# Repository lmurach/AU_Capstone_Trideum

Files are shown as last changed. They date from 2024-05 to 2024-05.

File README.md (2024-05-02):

# Cyber-Physical Teaching Kit
## General Description

The Cyber-Physical Teaching Kit (CPTK) is a miniature, modular building with a fully-functional control
system. The belief is that by building a robust model, students will better understand how to think about
potential cyber attacks. The code is mostly written in python for the Raspberry Pi 4, along with C++ code
for the Arduino. Students are more likely to encounter python and Arduino coding throughout high school
or college, which is why these two languages were chosen.

To see the full documentation, see the documentation PDF on our Github.

## Features

+ Sturdy, lightweight 3D printed frame with files available for re-printing
+ Accurate elevator with button controls on each floor and a re-calibration function
+ Temperature monitoring with an HVAC and duct work system for air conditioning
+ Security door system using RFID badges with a working door
+ Lights with individual floor motion detection
+ Full database for logging events, errors, and storing user configurations
+ Security assessment in pdf form detailing vulnerabilities, mitigation, and impact

## Links

+ [Github for open source code under the MIT license](https://github.com/lmurach)
+ [Security Assessment PDF](https://github.com/lmurach/AU_Capstone_Trideum/blob/ui_dev/TrideumCapstoneSecurityAssessment.pdf)

## Block Diagram



# Getting Started

An already constructed version of the CPTK was built for Trideum Corporation. The following are
instructions for running the program on the existing system.

## Running the App with a Monitor

This is the most ideal way to view the application, as the GUI is visible and intractable. If a monitor is
not available, see the next section.
1. Plug an HDMI cable, keyboard, and mouse into the Raspberry Pi and power the system. The Pi will
boot automatically.
2. Open the console using the icon at the top right of the screen or with the keyboard shortcut
CTRL+ALT+T
3. Run the application with the following command:
sudo python3 AU Capstone Trideum/application.py

## Running the App without a Monitor
Note that the GUI will not be accessible with this method.
1. Plug an Ethernet cable into the Pi and power the system. The Pi will boot automatically. Make sure
your Ethernet settings allow internet and file sharing.
2. For Windows users, install PuTTy.
3. Run the .exe file and enter in the following for the host name, then press enter:
```
cptk@raspberrypi.local
```


4. For macOS/Linux users, open the command prompt and enter the following command:
```
ssh cptk@[raspberrypi ip address]
```
To get the IP address, run ipconfig in the command line. Alternatively, follow the instructions for
Windows and install PuTTy.
5. Once connected, the command line will prompt for a password. The password for the cptk user is
CPTK-Project
The text will not show up while typing the password, but hitting enter will connect to the Pi.
6. Run the application with the following command:
```
sudo python3 AU Capstone Trideum/application.py -platform offscreen
```

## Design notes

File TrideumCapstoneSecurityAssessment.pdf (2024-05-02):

1

# Trideum Cyber-Physical Learning Model Security Assessment

### Assessment by Chris Stickney Last updated 4/25/2024

Cyber-Physical Learning Model by Wesley Cooke, Lauren Murach,

### Brycen Havens, and Chris Stickney

2

## Executive Summary

Since our system will be offline the majority of the time, the primary vulnerabilities this system

has are physical, only able to be taken advantage of by insiders and intruders. The primary

vulnerabilities found in the building include two critical vulnerabilities in the RFID door which

may allow illicit access to the restricted area it protects, and vulnerabilities in the temperature

sensors, which can lead to improper measurements being sent to the controller. These HVAC

vulnerabilities can lead to damage of expensive computational assets if the temperature gets too

cold or warm. Lastly, the motion sensors in use can be circumvented if they are unable to detect

thermal signatures moving, allowing intruders to not trigger alarms in the building after hours.

These issues are the most troublesome issues found, and should be addressed immediately to

improve site security and reduce risk.

3

### Contents

4

## Flipper Zero Can Bypass RFID Door Security

Threat Actor: Building Intruders and Insiders

Vulnerability: The Flipper Zero is a multi-purpose tool, with one of its capabilities being reading,

saving, and emulating RFID and NFC tags. This means that a user with a Flipper Zero is capable

of opening the RFID door without an RFID or NFC tag with access to the door, provided they

are able to read the RFID or NFC tag with the appropriate permissions to open the door.

Mitigation: Implement more complex RFID and NFC systems, such as an RFID or NFC system

that needs two RFID or NFC tags from the same card to gain access. It should also be noted that

the process the Flipper Zero uses to read RFID and NFC cards takes several seconds, making

successfully reading an RFID or NFC card more challenging for malicious actors. In addition,

the Flipper Zero tends to cause errors in the RFID reader code, as occasionally the signal sent is

not identical to the copied RFID or NFC tag.

Impact: Malicious actors can utilize this to bypass secure doors, gaining access to restricted

areas. Any systems located in these restricted areas will be vulnerable to physical tampering.

5

## PIR Motion Sensors Can Be Bypassed With Thermal

## Insulation

Threat Actor: Building Intruders and Insiders

Vulnerability: PIR motion sensors are unable to detect motion from objects with masked thermal

signatures since PIR sensors rely upon thermal changes to trigger the sensor.

Mitigation: Other forms of motion detection may be used, such as Microwave motion sensors,

which send a signal if a significant change is detected in the distance between the sensor and an

object. Microwave sensors can be extremely sensitive however and can read data through walls

at times. Other forms of motion sensors exist which have different upsides and downsides than

PIR sensors and Microwave sensors.

Impact: Security alerts for people intruding on the building after hours can be prevented, giving

malicious actors free access to the building (minus restricted areas), where they are free to do

what they please.

6

## Temperature Sensors Are Vulnerable to Physical

## Manipulation

Threat Actor: Building Intruders and Insiders

Vulnerability: TC74 temperature sensor is a contact-based temperature sensor, meaning very hot

or very cold objects may be applied to the sensor to manipulate readings and interrupt HVAC

operations.

Mitigation: Change the TC74 sensors out to a non-contact-based temperature, which operates by

reading infrared radiation of the surroundings. These can be interrupted by objects that cloak

thermal signatures being placed around the sensor, like an acrylic dome covering the sensor. The

best solution for both of these vulnerabilities is to place the temperature sensors in concealed, out

of reach locations to prevent tampering.

Impact: HVAC controls being manipulated can lead to uncomfortable working environments, or

in more extreme cases, damaged computer systems if the temperature becomes much too hot or

too cold. In this case, this can cause large financial loss of assets.

7

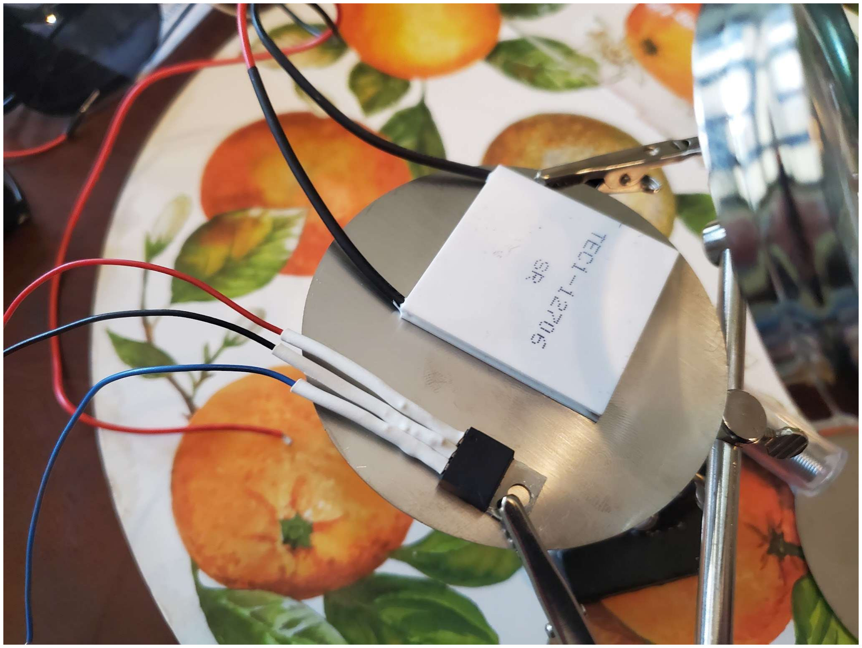
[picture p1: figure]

This image shows a similar contact based temperature sensor on a hot plate. A similar setup

could be used to manipulate the TC74 into running the HVAC too much. The opposite could also

occur if a cold object was attached to the TC74.

8

## System Stability Could Be Crippled By Online Attacks

## Which Ruin System Performance

Threat Actor: Malicious Outsiders and Insiders

Vulnerability: The control software’s operation could be interrupted by applications with high

performance draw, which could be activated by outside users to interrupt the system.

Mitigation: Critical cyber physical systems which can remain offline should remain offline to

prevent connections. The Raspberry Pi should be placed within a secure location to better protect

against unauthorized manipulation. Alternatively, if the system must be connected to the internet,

ensure proper security practices are in place and for added security against attacks, implement an

IDPS that can cut off connections. As a final line of protection, implementing revised code that

can improve the average Lyapunov stability of the system while under external stress should be

considered. This should not be an issue, as the system only needs to momentarily touch the

internet to set the system time.

Impact: If systems have inadequate safeguards against online attacks such as DDoS attacks or

False Data Injection attacks, the system’s performance and behavior could be altered, leading to

the system running behind or breaking entirely, needed to be restarted.

9

## Reed Switches May Be Manipulated With Strong Enough

## Magnets

Threat Actor: Insiders and Building Intruders

Vulnerability: Reed switches can be easily activated if not properly concealed or if too sensitive.

Magnets can be affixed to extra surfaces to make systems malfunction.

Mitigation: Getting reed switches with less sensitivity may work, but a better solution to ensure

the operation of the elevators is not interrupted is to make sure applying magnets in locations that

may disrupt the elevator is very challenging. Hall sensors would also have issues since they also

rely upon magnetic fields.

Impact: Strong enough magnets placed within or around the elevator cabin could interfere with

the reed sensors, sending faulty signals to the controller which may result in the elevator

stopping in the wrong spots.

10

## Physical Access to Wires May Allow Replay Attacks

Threat Actor: Insiders and Building Intruders

Vulnerability: If attackers are able to identify which wires are used for SPI or I2C, they could

mimic signals sent by sensors, such as the temperature sensor or RFID card reader. This can lead

to system malfunctions due to the system receiving erroneous data from malicious devices. It

should also be noted that the motion detection system also faces this issue, as an external device

could send a constant high or low signal to manipulate the program into thinking there is motion

when there isn’t or there isn’t motion when there is.

Mitigation: The best way to mitigate this threat is to ensure that all wiring is protected from

tampering. Exposed wiring can be disconnected from their sensors and connected to a malicious

device which sends false information. New log alerts could be made which record when

unreasonable values are detected for the RFID reader or temperature sensors.

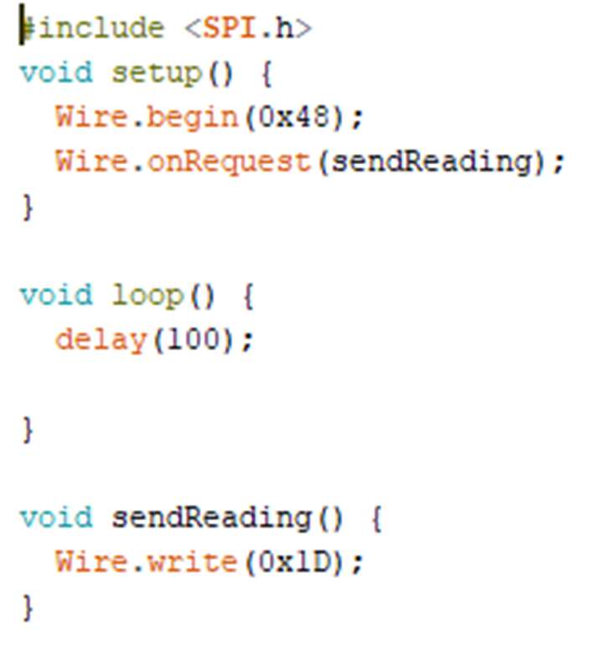
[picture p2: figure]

11

This simple program is able to send a false temperature reading of 29°C, which equals around

84°F. It should be noted that this program is run on an Arduino which uses 3.3V logic like a

Raspberry Pi. The erroneous value being sent will force the HVAC system into cooling the floor

with the TC74 with address 0x48. This code could be altered to send a constant value below the

activation threshold to prevent the HVAC from turning on.

Impact: HVAC controls being manipulated can lead to uncomfortable working environments, or

in more extreme cases, damaged computer systems if the temperature becomes much too hot or

too cold. In this case, this can cause large financial loss of assets. A similar attack using more

advanced techniques may also be performed on the RFID door, where information could be

captured and retransmitted by a third party device, allowing the door to open without an RFID

device being used. This allows illicit access to restricted areas that are supposed to be protected

by these doors, which can lead to restricted system tampering.

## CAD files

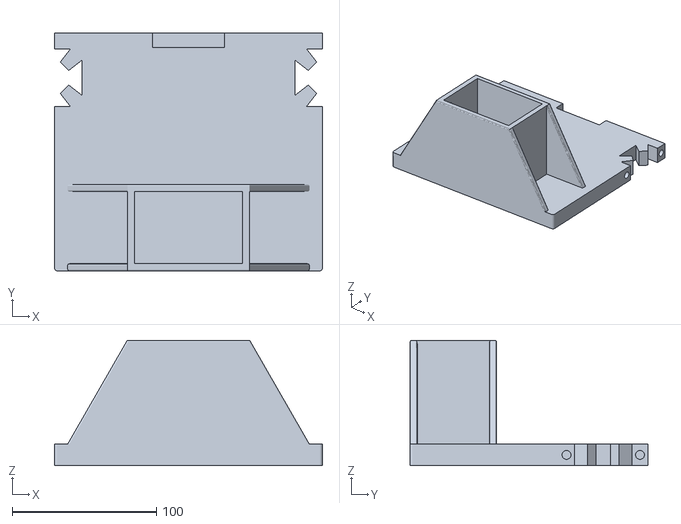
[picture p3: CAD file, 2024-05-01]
allFrameParts/Base Frame/Elevator Base (x1).stl
186.0 x 165.1 x 87.0

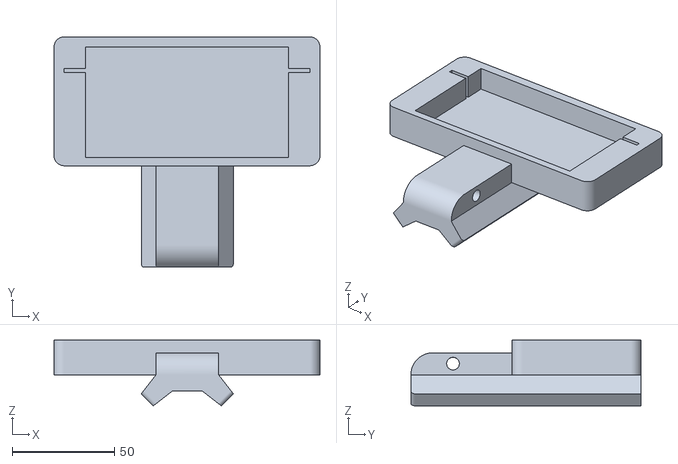
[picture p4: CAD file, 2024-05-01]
allFrameParts/Basement Floor/HVAC Mount (x1).stl
130.0 x 112.5 x 32.1

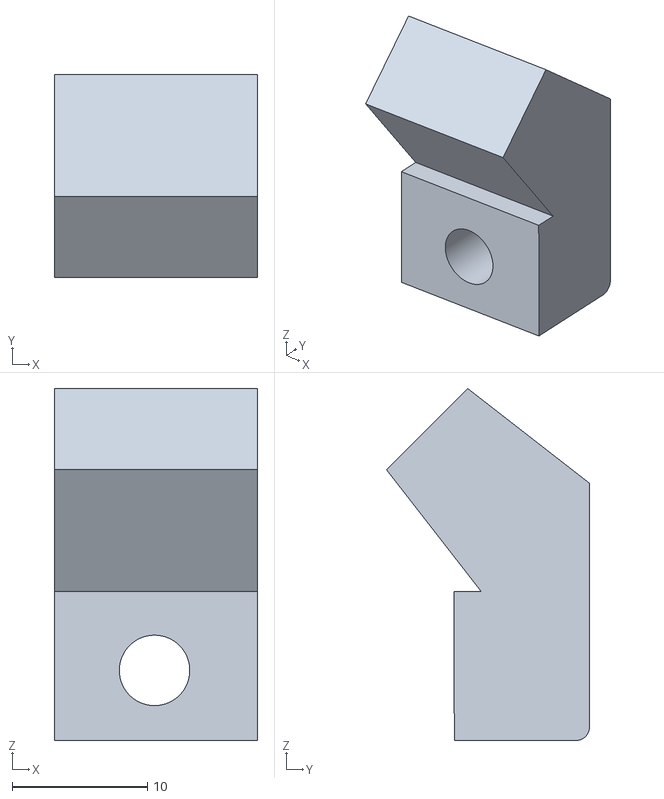
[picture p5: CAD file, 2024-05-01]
allFrameParts/Clamps/Short Clamp (x4).stl
15.0 x 15.0 x 26.0

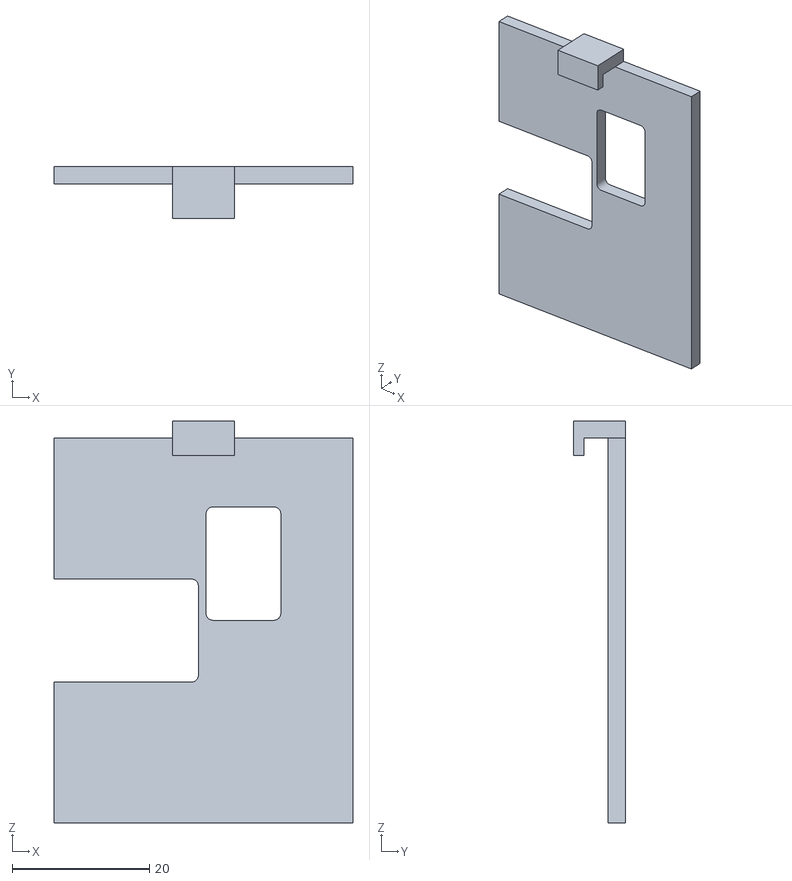
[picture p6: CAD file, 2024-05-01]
allFrameParts/Elevator/Push Button Mount Cover (x3).stl
43.5 x 7.50 x 58.5

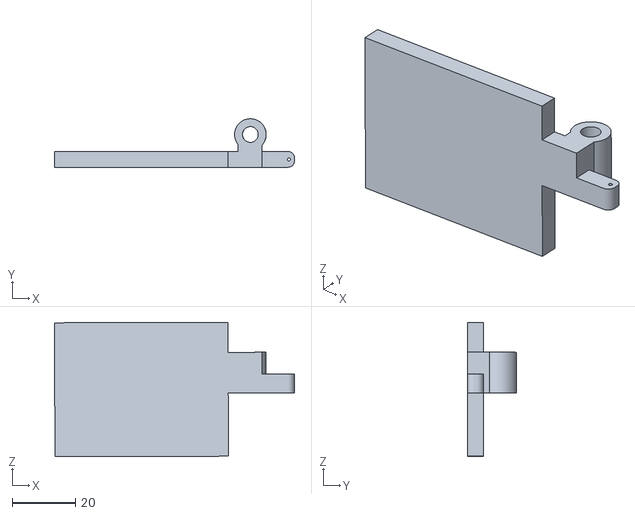
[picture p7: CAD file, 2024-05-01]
allFrameParts/HVAC Duct System/HVAC Door (x3).stl
76.1 x 15.4 x 42.6

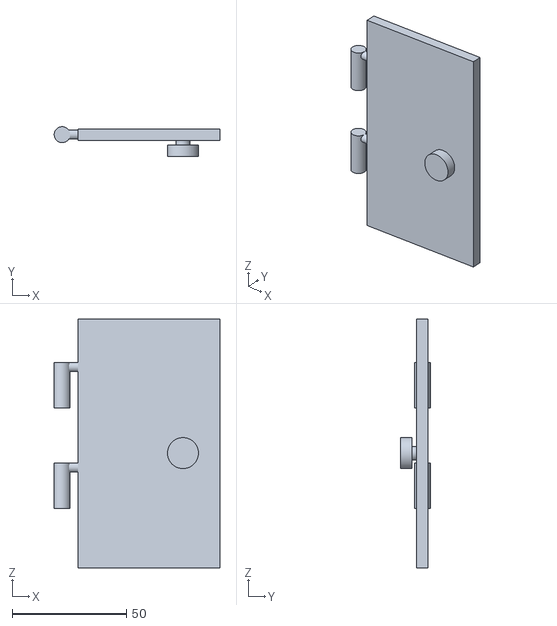
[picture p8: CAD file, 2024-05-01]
allFrameParts/RFID Door/Door (x1).stl
72.5 x 13.0 x 109.0

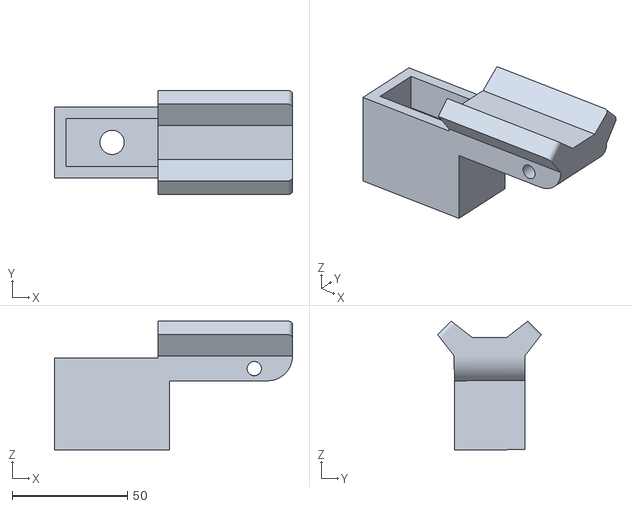
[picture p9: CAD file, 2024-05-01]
allFrameParts/Sensor Mounts/MotionTemp Mount (x2).stl
103.3 x 45.0 x 55.9

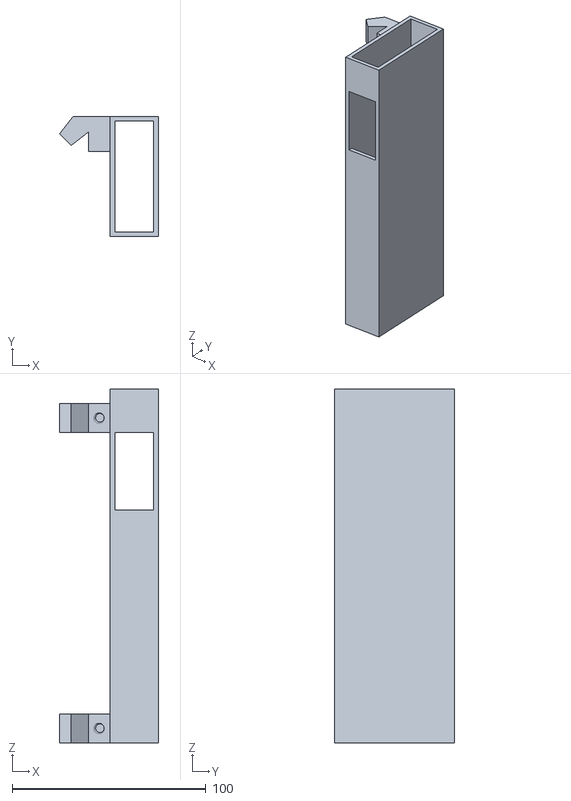
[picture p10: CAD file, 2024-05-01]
allFrameParts/Wire Concealment/Wire Channel B1 R (x1).stl
51.0 x 62.0 x 182.5

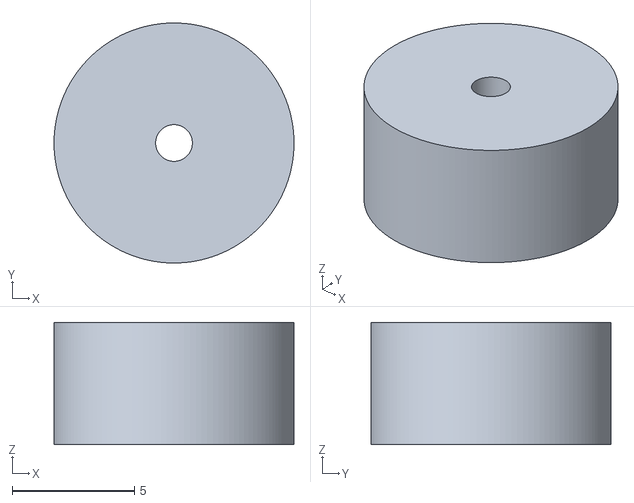
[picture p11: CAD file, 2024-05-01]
allFrameParts/Wire Floor/Solder Board Peg (x4).stl
9.80 x 9.80 x 5.00

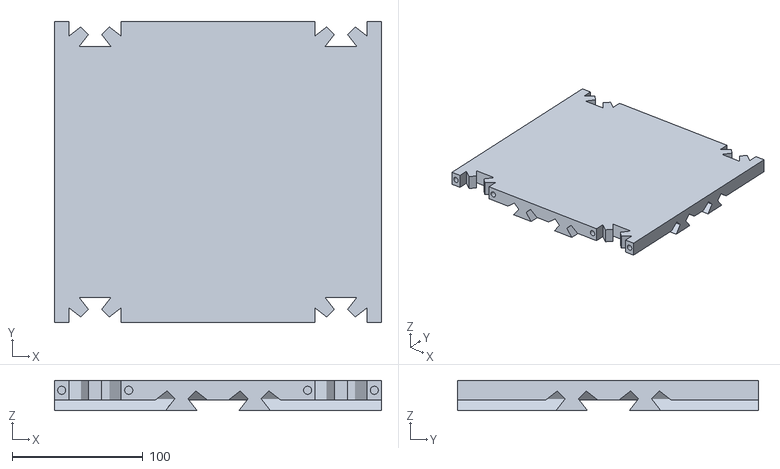
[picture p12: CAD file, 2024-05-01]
allFrameParts/Base Frame/FirstTop Floor (x2).stl
250.0 x 229.9 x 23.0

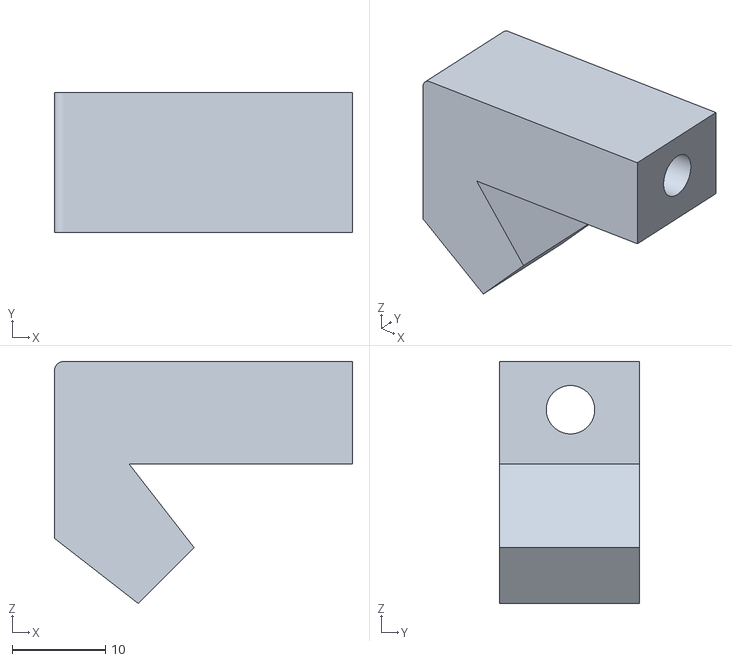
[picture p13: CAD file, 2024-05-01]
allFrameParts/Basement Floor/HAVC Mount Clamp (x2).stl
32.0 x 15.0 x 26.0

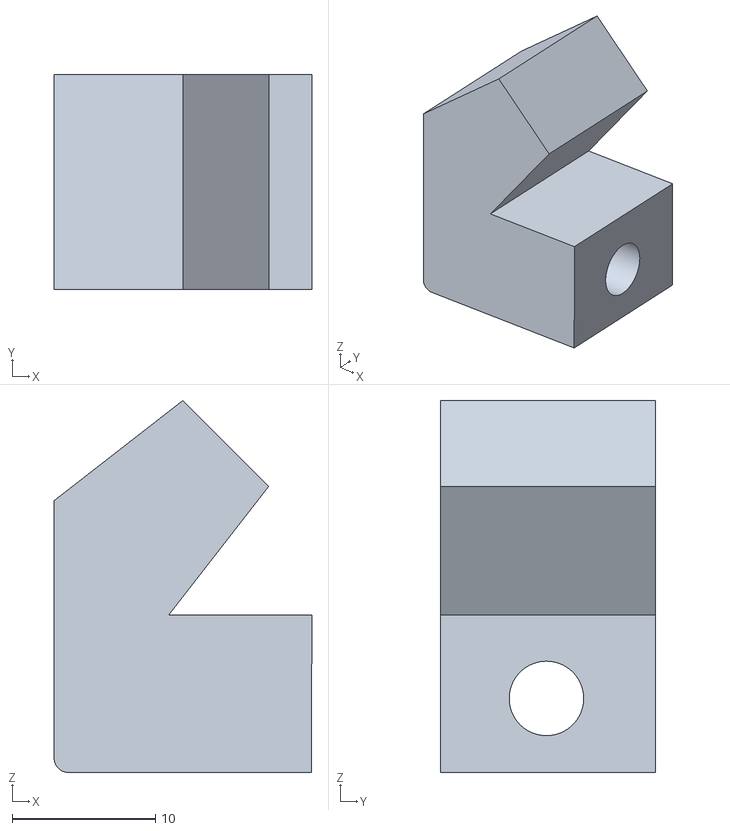
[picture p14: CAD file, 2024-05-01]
allFrameParts/Clamps/Standard Clamp (x19).stl
18.0 x 15.0 x 26.0

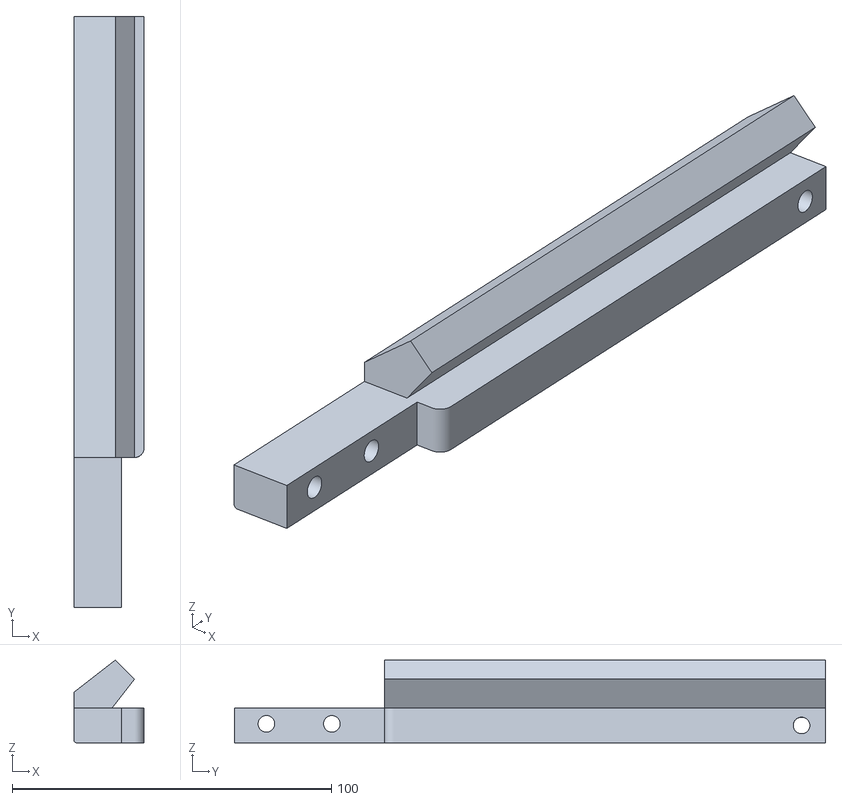
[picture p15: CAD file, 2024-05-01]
allFrameParts/Elevator/Elevator Top Mount (x1).stl
22.0 x 185.2 x 26.0

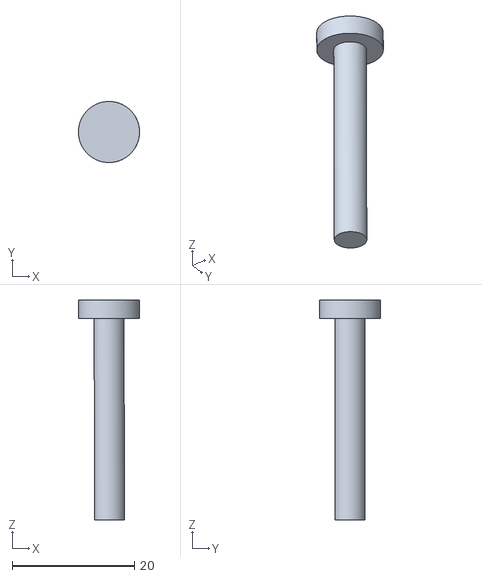
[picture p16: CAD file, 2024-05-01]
allFrameParts/HVAC Duct System/HVAC Pin (x3).stl
10.0 x 10.00 x 36.0

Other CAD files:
allFrameParts/RFID Door/RFID Door Frame (x1).stl
allFrameParts/Wire Concealment/NeoPixel Cover (x3).stl
allFrameParts/Wire Floor/Wire Cover Panel Short (x1).stl
allFrameParts/Base Frame/Support Beam 4mm, 100mm (x4).stl
allFrameParts/Base Frame/Base Frame Clamp (x16).stl
allFrameParts/Base Frame/Base Frame Clamp L (x2).stl
allFrameParts/Base Frame/Base Frame Clamp R (x2).stl
allFrameParts/Base Frame/Basement Floor (x1).stl
allFrameParts/Base Frame/Second Floor (x1).stl
allFrameParts/Base Frame/Support Beam 4mm, 200mm (x12).stl
allFrameParts/Base Frame/Wire Floor Base (x1).stl
allFrameParts/Elevator/Push Button Mount (x3).stl
allFrameParts/HVAC Duct System/HVAC Duct 1 (x1).stl
allFrameParts/HVAC Duct System/HVAC Duct 2 (x1).stl
allFrameParts/HVAC Duct System/HVAC Duct 3 (x1).stl
allFrameParts/HVAC Duct System/HVAC Duct 4 (x1).stl
allFrameParts/HVAC Duct System/HVAC Duct 5 (x1).stl
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

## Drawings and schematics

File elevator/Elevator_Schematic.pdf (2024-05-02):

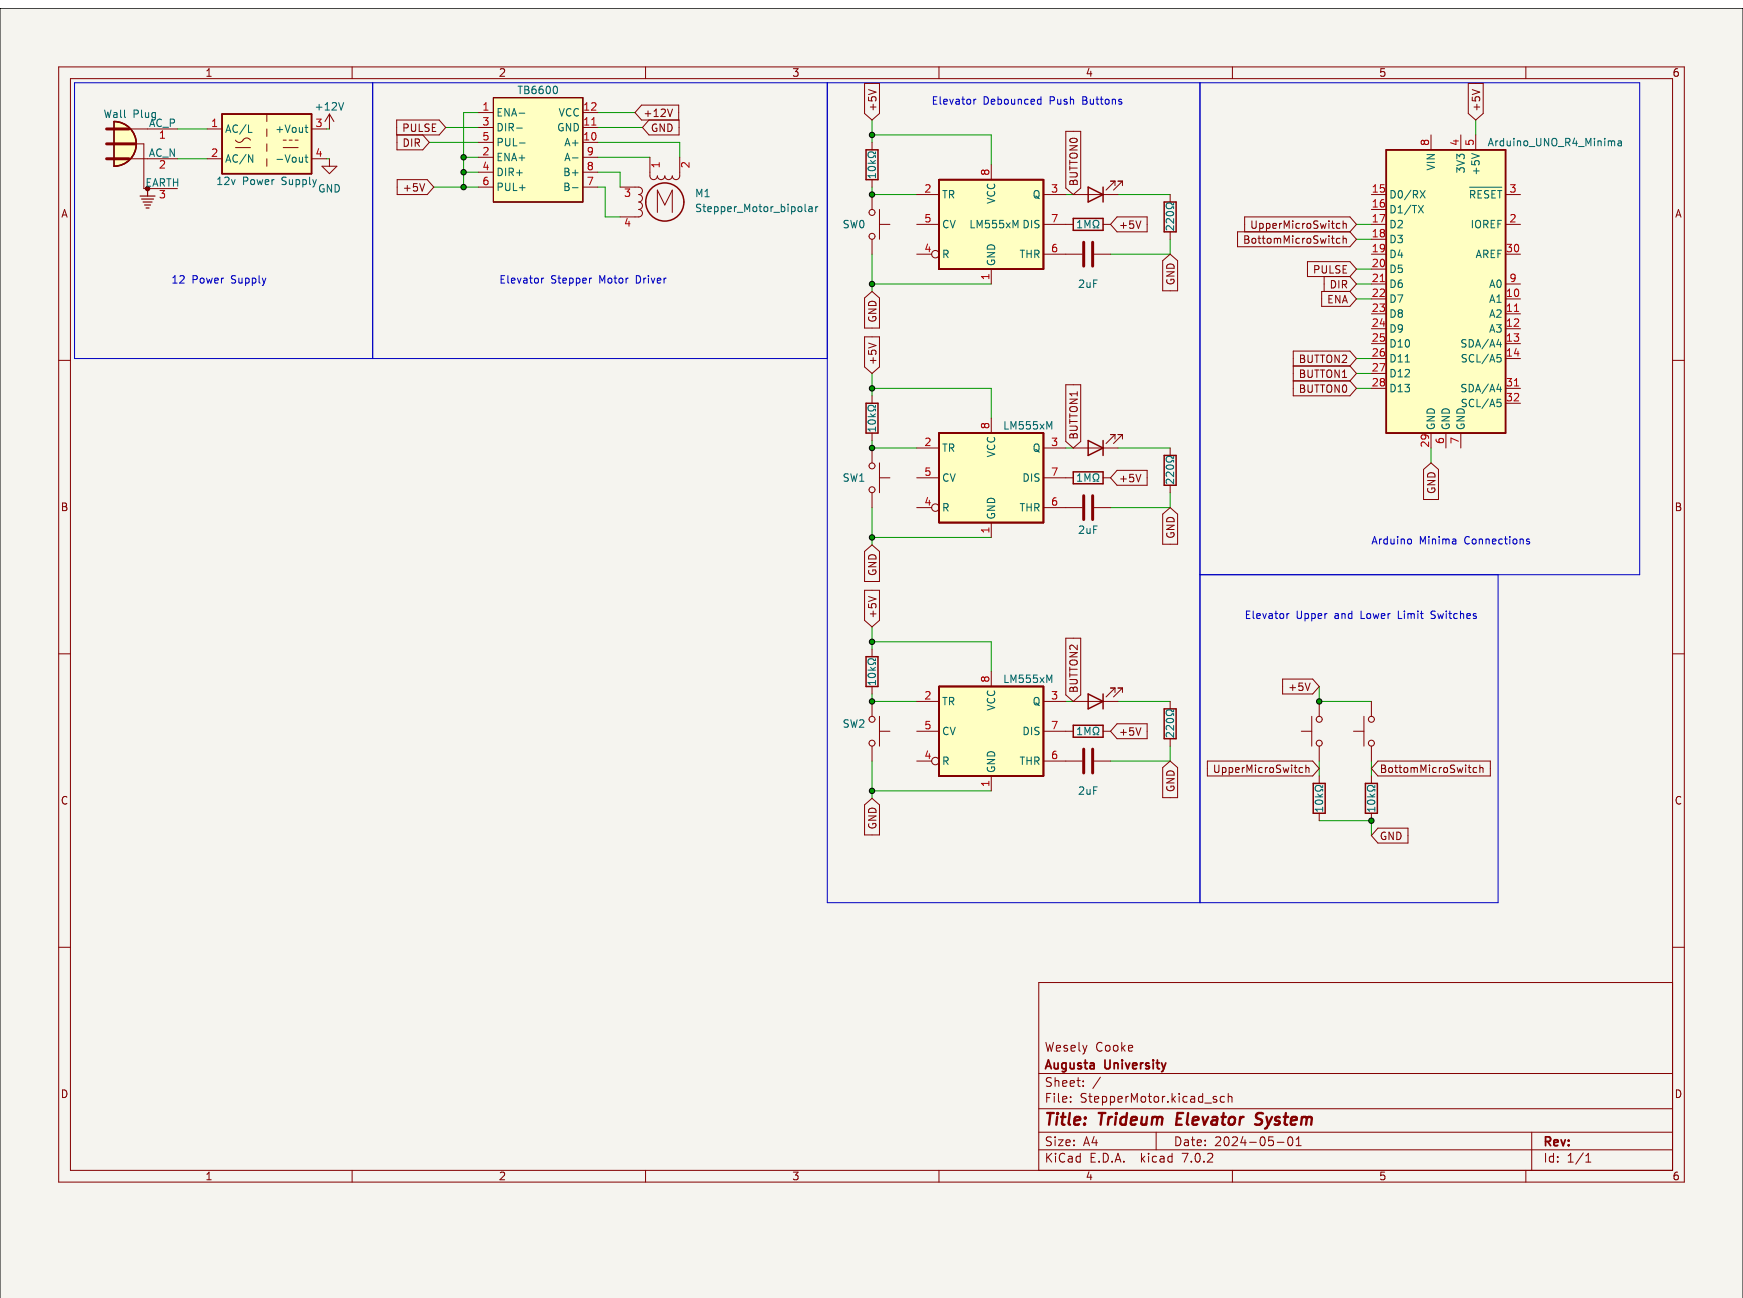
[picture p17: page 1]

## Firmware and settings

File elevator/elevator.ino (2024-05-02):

/* 
 *  Author     : Wesley Cooke
 *  Date       : 04/01/2024
 *  Description: Elevator system using 3 push buttons with hardware debounce. 
 *               Tracks the state of the buttons being pushed and relays that 
 *               information over UART to the pi. 
 *               
 *               :TODO: Refactor movement methods. The main stepper motor driver
 *                      commands and polling functions can be refactored into 
 *                      a separate method. The moveElevatorUp and moveElevatorDown 
 *                      are two prime examples of this. 
 *                      
 *               :TODO: Refactor the checkButtons method. Functaionlity for the q
 *                      can be pulled out and an index for the floor can be passed. 
 *     
 *               
 */

// Button Pins
const int b0 = 13;
const int b1 = 12; 
const int b2 = 11;

// Motor Control Pins
const int pulse = 5; 
const int dir   = 6;
const int ena   = 7;

// Micro Switch Connections
const int botLimitSwitch = 3;
const int upLimitSiwtch  = 2; 

// How do we convert a step to a milimeter?
// The belt has a pitch of 2mm and the timing pully has 30 teeth. 
// This means that one full 360 degree rotation will move the gantry 30*2 = 60mm. 
// On the microstepper driver we have 200 steps set to to move the motor 360 degrees.
// The dimensional analysis is simple from here: 
// 200(steps/60mm) = 3.33 steps/mm.
float mmToSteps = 3.33;

// These are timing variables used to
// determine how long the elevator has been at a floor.
unsigned long visiting;
unsigned long state_sent; 

// These variables are for polling the states of the buttons. 
bool bs0;
bool bs1;
bool bs2;

// Queue Tracking variables 
int floors_requested[3] = {-1, -1, -1}; // The Queue for requested floors
bool already_requested[3];              // Keep track of its its alreayd in the Queue.  

int requested_num = 0;                  // num items in queue 
int req_p;                              // pointer for the floor to visit 
int current_step;                       // What step are we on? 
int floor_locations[3];                 // Will update based on limit switch values
int current_floor = -1;                 // -1 for not at a floor. 0, 1, 2 other wise. 

void moveElevatorUp(int numMM)
{
  int steps = numMM * (mmToSteps); // Convert the numMM to a set number of steps 

  // Set the direction to up and make sure elevator is enabled
  digitalWrite(dir, LOW);
  digitalWrite(ena, HIGH);
  // pulse for the required amount of steps
  for(int i=0; i<steps; i++)
  {
    // Continue polling our buttons and updating the queue and GUI. 
    checkButtons();
    printState();
    
    // If the upper limit switch is triggered, don't continue.
    // We have reached the top floor.  
    if (digitalRead(upLimitSiwtch) == HIGH)
    {
      digitalWrite(ena, LOW);
      digitalWrite(ena, HIGH);
      break; 
    }
    // Provide a pulse to the stepper motor driver. 
    digitalWrite(pulse, HIGH);
    delayMicroseconds(1000);
    digitalWrite(pulse, LOW);
    delayMicroseconds(1000);
  }
}

void moveElevatorDown(int numMM)
{
  
  int steps = numMM * (mmToSteps); // Convert numMM to a set number of steps

  // Set the direction to down 
  digitalWrite(dir, HIGH);
  digitalWrite(ena, HIGH);
  for(int i=0; i<steps; i++)
  {
    // Continue polling the buttons and updating the queue and GUI. 
    checkButtons();
    printState();
    // If the lower limit switch is trigered, don't continue.
    // We are at the bottom floor. 
    if (digitalRead(botLimitSwitch) == HIGH)
    {
      digitalWrite(ena, LOW);
      digitalWrite(ena, HIGH);
      break;
    }
    // Provide a pulse to the stepper motor. 
    digitalWrite(pulse, HIGH);
    delayMicroseconds(1000);
    digitalWrite(pulse, LOW);
    delayMicroseconds(1000);
  }
}

void goToLowerLimit()
{
  // Method to set the elevator to the lowest floor.

  // Set the direciton to down
  digitalWrite(dir, HIGH);
  digitalWrite(ena, HIGH);
  // Continue pulsing until we hit the lower limit switch. 
  while(digitalRead(botLimitSwitch) == LOW)
  {
    // Continue polling the buttons and updating the queue and GUI.  
    checkButtons();
    printState();
    digitalWrite(pulse, HIGH);
    delayMicroseconds(1000);
    digitalWrite(pulse, LOW);
    delayMicroseconds(1000);
  }
  // set the current step to 0
  current_step = 0;
}

void goToUpperLimit()
{
  // Method to set the elevator to the highest floor.

  // set the elevator to move up 
  digitalWrite(dir, LOW);
  digitalWrite(ena, HIGH);

  // Continue going up until the upper limit switch is hit. 
  while(digitalRead(upLimitSiwtch) == LOW)
  {
    // Continue polling the buttons and updating the queue and GUI. 
    checkButtons();
    printState();
    digitalWrite(pulse, HIGH);
    delayMicroseconds(1000);
    digitalWrite(pulse, LOW);
    delayMicroseconds(1000);
    // Increase the step number.
    current_step++;
  }
}

void setup() 
{
  // Set the buttons as inputs 
  pinMode(b0, INPUT);
  pinMode(b1, INPUT);
  pinMode(b2, INPUT); 

  // Set the motor control pins as outputs
  pinMode(pulse, OUTPUT);
  pinMode(dir, OUTPUT);
  pinMode(ena, OUTPUT);

  // Start serial comms for the GUI. 
  Serial.begin(115200);

  // Calibrate the elevator
  goToLowerLimit();
  goToUpperLimit();

  // Set the first floor to be halfway between the upper and lower limits
  floor_locations[0] = 0;
  floor_locations[1] = current_step/2; 
  floor_locations[2] = current_step; 

  // Go back to the bottom floor
  goToLowerLimit();
  // Set the req_p to the beginning of the queue. 
  req_p = 0;
  current_floor = 0; 
}

void checkButtons()
{
  // This method must be polled to ensure the button presses are responded to

  // Read the buttons.
  bs0 = digitalRead(b0);
  bs1 = digitalRead(b1);
  bs2 = digitalRead(b2);

  // If the bottom floor button has been pressed. 
  if (bs0)
  {
    // If our queue isn't full and this floor isn't already in the queue
    if (requested_num != 3 and already_requested[0] != 1)
    {
      // If the current pointer for the queue is open, 
      // place the floor there. 
      if(floors_requested[req_p] == -1)
      {
        floors_requested[req_p] = 0;
      }
      // If the next pointer for the queue is open, place it there
      else if(floors_requested[(req_p+1)%3] == -1)
      {
        floors_requested[(req_p+1)%3] = 0; 
      }
      else // If the final pointer for the queue is open, place it there
      {
        floors_requested[(req_p+2)%3] = 0; 
      }
      // Increment the number of items in the queue. 
      // Set this floor as already having been added. 
      requested_num += 1;
      already_requested[0] = 1;
    }
  }
  // The comments are carbon copies of the above. The inner functionality 
  // should be made a function call, passing in the floor number. Hence the :TODO:
  if (bs1)
  {
    if (requested_num != 3 and already_requested[1] != 1)
    {
      if(floors_requested[req_p] == -1)
      {
        floors_requested[req_p] = 1;
      }
      else if(floors_requested[(req_p+1)%3] == -1)
      {
        floors_requested[(req_p+1)%3] = 1; 
      }
      else 
      {
        floors_requested[(req_p+2)%3] = 1; 
      }
      requested_num += 1;
      already_requested[1] = 1;
    }
  }
  if (bs2)
  {
    if (requested_num != 3 and already_requested[2] != 1)
    {
      if(floors_requested[req_p] == -1)
      {
        floors_requested[req_p] = 2;
      }
      else if(floors_requested[(req_p+1)%3] == -1)
      {
        floors_requested[(req_p+1)%3] = 2; 
      }
      else 
      {
        floors_requested[(req_p+2)%3] = 2; 
      }
      requested_num += 1;
      already_requested[2] = 1;
    }
  }
}

void loop() 
{
  // Continue polling the buttons and updating the queue and GUI.
  checkButtons(); 
  printState();

  // Get the floor we shoud visit next. 
  int floor_to_visit = floors_requested[req_p];

  // If it's the bottom floor 
  if (floor_to_visit == 0)
  {
    // Go to the bottom and set the current floor
    goToLowerLimit();
    current_floor = 0;

    // Stay for 2 seconds
    visiting = millis(); 
    while((millis() - visiting)< 2000)
    {
      // Continue polling the buttons and updating the queue and GUI.
      checkButtons();
      printState();
    }

    // Take this item out of the queue and reset it's tracking variables.
    // Increment the queue pointer. 
    already_requested[0] = 0;
    floors_requested[req_p] = -1;
    req_p = (req_p + 1)%3;
    requested_num--;
    // Set the current step number. 
    current_step = 0;
  }
  // If it's the top floor 
  if (floor_to_visit == 2)
  {
    // Go to the top and set the current floor. 
    goToUpperLimit();
    current_floor = 2;
    
    // Stay for 2 seconds 
    visiting = millis(); 
    while((millis() - visiting)< 2000)
    {
      // Continue polling the buttons and updating the queue and GUI.
      checkButtons();
      printState();
    }

    // Take the floor out of the queue and reset it's tracking variables. 
    already_requested[2] = 0;
    floors_requested[req_p] = -1;
    req_p = (req_p + 1)%3;
    requested_num--;
    // set the current step from calibration. 
    current_step = floor_locations[2];
  }

  // If it's the middle floor 
  if (floor_to_visit == 1)
  {
    // Are we above? 
    if(current_step > floor_locations[1])
    {
      // Move elevator down
      moveElevatorDown((current_step - floor_locations[1])/mmToSteps); 
      
    }
    // are we are below?
    else if (current_step < floor_locations[1])
    {
      // Move elevator up 
      moveElevatorUp((floor_locations[1] - current_step)/mmToSteps); 
    }

    current_floor = 1;
    visiting = millis(); 
    while((millis() - visiting)< 2000)
    {
      // Continue polling the buttons and updating the queue and GUI.
      checkButtons();
      printState();
    }
    // Reset this floor
    already_requested[1] = 0;
    floors_requested[req_p] = -1;
    req_p = (req_p + 1)%3;
    requested_num--;
    current_step = floor_locations[1];
  }
}

void printState()
{
  // This method uses a software debounce so we aren't 
  // sending data over too frequently. 
  // Get the current time
  unsigned long current = millis();

  // If we haven't sent something in the past 0.5 seconds. 
  if((current - state_sent) > 500)
  {
    // Send our data over with a starting byte and end byte. 
    Serial.println("S");
    Serial.println(floors_requested[0]);
    Serial.println(floors_requested[1]); 
    Serial.println(floors_requested[2]);
    Serial.println(current_floor); 
    Serial.println("E");
    // remeber that we just sent something. 
    state_sent = current;
  }
}

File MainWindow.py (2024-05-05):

from main_form import Ui_MainWindow
from PyQt5 import QtWidgets, QtCore
from database import Database
from door import Door
from tempSensor import TempControl
from background_main import BackgroundMain
import sys
import RPi.GPIO as GPIO
from PyQt5.QtCore import QThread

class OurMainWindow():
    """ 
    This object sets up the UI elements and has control over all updates
    that are displayed on the UI.
    """

    def __init__(self, adoor:Door, adb: Database):
        """
        Constructor. Our UI needs a Door object and a Database object.
        The door object will give us updates for the RFID door. 
        The database object will allow us to pull information from our database and 
        store new data there.
        """
        # Create a thread 
        self.thread = QThread()

        # Create a QApplication using Pyqt5
        self.app = QtWidgets.QApplication(sys.argv)
        self.MainWindow = QtWidgets.QMainWindow()

        # Load the UI class that is generated from piuic5
        self.ui = Ui_MainWindow()

        # Allow the UI to use our QMainWindow object
        self.ui.setupUi(self.MainWindow)

        # Keep the door and database as class members.
        self.door = adoor
        self.db = adb
        self.bg_task_manager = BackgroundMain()
        # self.bg_elevator     = BGElevator()

        # Set up functionality for the dials, alarm, door, and logs.
        self.setUpDials()
        self.setUpAlarm()
        self.setUpDoor()
        self.set_up_logs()
        self.setUpCheckBoxes()

        self.ui.tabWidget.setCurrentIndex(0)

        # These are style sheets that we swap between for colors.
        self.GREEN  = "border: 3px solid green;\nbackground-color: lightGreen;\n"
        self.RED    = "border: 3px solid red;\nbackground-color: pink;\n"
        self.GREY   = "border: 3px solid grey;\nbackground-color: lightGrey;\n"
        self.YELLOW = "border: 3px solid yellow;\nbackground-color: lightYellow;\n"

        self._previous_elevator_floor = 0

    def show(self):
        """ This method will start the QApplication and present the user with the GUI. """
        self.MainWindow.show()
        sys.exit(self.appExec())

    def appExec(self):
        self.app.exec_()
        self.bg_task_manager.running = False
        self.thread.quit()
        self.thread.wait() 
        
        for temp_sensor in self.bg_task_manager.temp_sensors:
            temp_sensor.pwm.stop()


    def update_top_floor_dials(self):
        """ This method will activate when a user rotates the top dial from the control view."""
        # Update the text with the new value for the control and split views.
        dial_temp_value = self.ui.top_floor_hvac_dial.value()
        self.ui.top_floor_activate_on.setText(f"Cool to: {dial_temp_value}°F")
        self.ui.top_floor_activate_on_split.setText(f"{dial_temp_value}°F")
        TempControl.set_temps[2] = dial_temp_value
        # Set the split view dial to the same value.
        self.ui.top_floor_hvac_dial_split.setValue(dial_temp_value)

    def update_top_floor_dials_split(self):
        """ This method will activate when a user rotates the top dial from the split view."""
        # Update the text with the new values for the control and split views.
        dial_temp_value = self.ui.top_floor_hvac_dial_split.value()
        self.ui.top_floor_activate_on.setText(f"Cool to: {dial_temp_value}°F")
        self.ui.top_floor_activate_on_split.setText(f"{dial_temp_value}°F")
        # update the background object's set value
        TempControl.set_temps[2] = dial_temp_value
        # Set the control view dial to the same value.
        self.ui.top_floor_hvac_dial.setValue(dial_temp_value)

    def update_mid_floor_dials(self):
        """ This method will activate when a user rotates the middle dial from the control view."""
        # Update the text with the new values for the control and split views.
        dial_temp_value = self.ui.middle_floor_hvac_dial.value()
        self.ui.middle_floor_activate_on.setText(f"Cool to: {dial_temp_value}°F")
        self.ui.middle_floor_activate_on_split.setText(f"{dial_temp_value}°F")
        # update the background object's set value
        TempControl.set_temps[1] = dial_temp_value
        # Set the split view dial to the same value.
        self.ui.middle_floor_hvac_dial_split.setValue(dial_temp_value)

    def update_mid_floor_dials_split(self):
        """ This method will activate when a user rotates the middle dial from the split view."""
        # Update the text with the new values for the control and split views.
        dial_temp_value = self.ui.middle_floor_hvac_dial_split.value()
        self.ui.middle_floor_activate_on.setText(f"Cool to: {dial_temp_value}°F")
        self.ui.middle_floor_activate_on_split.setText(f"{dial_temp_value}°F")
        # update the background object's set value
        TempControl.set_temps[1] = dial_temp_value
        # Set the control view dial to the same value.
        self.ui.middle_floor_hvac_dial.setValue(dial_temp_value)

    def update_bot_floor_dials(self):
        """ This method will activate when a user rotates the bottom dial from the control view."""
        # Update the text with the new values for the control and split views.
        dial_temp_value = self.ui.bottom_floor_hvac_dial.value()
        self.ui.bottom_floor_activate_on.setText(f"Cool to: {dial_temp_value}°F")
        self.ui.bottom_floor_activate_on_split.setText(f"{dial_temp_value}°F")
        # update the background object's set value
        TempControl.set_temps[0] = dial_temp_value
        # Set the split view dial to the same value.
        self.ui.bottom_floor_hvac_dial_split.setValue(dial_temp_value)
    
    def update_bot_floor_dials_split(self):
        """ This method activates when a user rotates the bottom dial from the split view."""
        # Update the text with the new values for the control and split views.
        dial_temp_value = self.ui.bottom_floor_hvac_dial_split.value()
        self.ui.bottom_floor_activate_on.setText(f"Cool to: {dial_temp_value}°F")
        self.ui.bottom_floor_activate_on_split.setText(f"{dial_temp_value}°F")
        # update the background object's set value
        TempControl.set_temps[0] = dial_temp_value
        # Set the control view dial to the same value.
        self.ui.bottom_floor_hvac_dial.setValue(dial_temp_value)

    def setUpDials(self):
        """ 
        This method configures the dials with a proper range
        and connects them to their corresponding functions for updating 
        the rest of the Ui. 
        """
        temps = self.db.get_config_temperature_array() # basement to top
        print(f"Temps: {temps}")
        if len(temps) == 0:
            temps = [70, 70, 70]
        TempControl.set_temps = temps
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

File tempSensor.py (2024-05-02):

"""
Author  : Brycen Havens, Lauren Murach
Date    : 03/15/2024
Purpose : Turns HVAC system on and off depending on the temperature the floor 
is set too.
"""

import time
from datetime import datetime
from rpi_hardware_pwm import HardwarePWM
import RPi.GPIO as GPIO
import smbus2

from database import Database
from typing import Tuple

class TempControl:
    '''This class controls all of the temperature readings from the temperature
    sensors, the vent servomotors, and the HVAC cooler unit turning on or off.
    '''
    # Define I2C bus number
    bus_number = 1
    # Initialize I2C bus
    bus = smbus2.SMBus(bus_number)
    TEMP_ERROR_VAL = -65
    HVAC_cooler_pin = 6
    and_gate_input_pins = [13, 23, 26]
    set_temps = [75, 75, 75]
    servo_turn = 1
    servo_busy_counter = 0
    pwm = HardwarePWM(pwm_channel=1, hz=50, chip=0)

    def __init__(self, floor:int, address:int):
        self.floor = floor
        self.address = address
        self.prev_temp = self.TEMP_ERROR_VAL
        # ^ random high value so it doesn't try to turn on when the program
        # starts up
        self.prev_HVAC_is_on = False
        self.is_connected = True
        self.database = Database()
        print(GPIO.getmode())
        GPIO.setmode(GPIO.BCM)
        GPIO.setup(TempControl.and_gate_input_pins[self.floor], GPIO.OUT)
        GPIO.setup(self.HVAC_cooler_pin, GPIO.OUT)

    def get_temp_if_changed(self) -> Tuple[bool, int]:
        '''Returns a boolean if there was a log (error or update) to the
        database. This way the GUI can update the logs page or the
        temperature. The floor_turn is a very simple implementation of a
        mutex algorithm'''
        is_changed, temp = self._read_temperature()
        if (temp > TempControl.set_temps[self.floor]+2 and
            self.floor == TempControl.servo_turn and
            TempControl.servo_busy_counter == 0 and
            self.prev_HVAC_is_on is False
            ):
            self.change_HVAC_vent_state(True)
            self.prev_HVAC_is_on = True
            is_changed = True
            TempControl.servo_busy_counter = 2
        if (temp <= TempControl.set_temps[self.floor]-2 and
            self.floor == TempControl.servo_turn and
            TempControl.servo_busy_counter == 0 and
            self.prev_HVAC_is_on is True
            ):
            self.change_HVAC_vent_state(False)
            self.prev_HVAC_is_on = False
            is_changed = True
            TempControl.servo_busy_counter = 2
        return (is_changed, temp)

    def _read_temperature(self) -> Tuple[bool, int]:
        '''The purpose of the following function is to return the 
        temperature of a requested Floor's sensor'''
        try:
            temperature_data = self.bus.read_byte_data(self.address, 0x00)
            # Read temperature register (0x00)
        except IOError:
            if self.is_connected:
                self.is_connected = False
                self._log_HVAC_error(0)
            return (True, self.TEMP_ERROR_VAL)
        temperature_fahrenheit = temperature_data * 9/5 + 32
        if not self.is_connected:
            self._log_HVAC_error(1)
            self.is_connected = True
            return (True, temperature_fahrenheit)
        # Read temp data and convert it to F,
        # (each LSB represents 1 degree Celsius)
        return (False, temperature_fahrenheit)

    def _log_HVAC_error(self, state:int) -> None:
        '''logs if the temperature sensor is disconnected/reconnected from/to
        the bus. This is possible by seeing if the I2C address is missing'''
        self.database.create_HVAC_log(
            datetime.now(),
            self.floor,
            1,
            state
        )

    def change_HVAC_vent_state(self, is_on:bool) -> bool:
        '''Controls the GPIO pins so that the HVAC vent can open or close.
        First, the PWM signal stops while the pins are changing to reduce jitter
        on the vents. Then the select pins change to high or low depending on
        the floor, then the correct servo moves with a PWM signal.'''
        if is_on:
            self._open_servo()
        else:
            self._close_servo()

    @staticmethod
    def change_HVAC_cooler_state(is_on:bool) -> None:
        '''If all vents are closed, the HVAC turns off.'''
        GPIO.output(TempControl.HVAC_cooler_pin, is_on)

    def _open_servo(self):
        '''The PWM is shared so the output must set all other GPIO pins
        to low that are connected to other AND gates and then set the correct
        pin high for its own AND gate. 5.25 is 20 degrees
        (0 is 5 and 180 is 10)'''
        GPIO.output(TempControl.and_gate_input_pins, GPIO.LOW)
        GPIO.output(TempControl.and_gate_input_pins[self.floor], GPIO.HIGH)
        TempControl.pwm.start(5.25)


    def _close_servo(self):
        '''The PWM is shared so the output must set all other GPIO pins
        to low that are connected to other AND gates and then set the correct
        pin high for its own AND gate. 8.3 is 120 degrees
        (0 is 5 and 180 is 10)'''
        GPIO.output(TempControl.and_gate_input_pins, GPIO.LOW)
        GPIO.output(TempControl.and_gate_input_pins[self.floor], GPIO.HIGH)
        TempControl.pwm.start(8.3)

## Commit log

2024-02-14 Is this even working? Added my first iteration of the Neopixel and Motion Sensor code. Requires testing
2024-02-19 Raspberry Pi Files
    Git hub should add back password auth -.-
2024-02-19 Updated code to properly light up the correct amount of pixels. Code functions as expected when connected to a motion sensor and neopixels
2024-02-28 Cleaned up Motion sensor code, and reworked it into a class. Interrupts are no longer used.
    [NeopixelsMotionTestIntegration.py]
2024-03-16 Temp Sensor code progress
2024-03-18 Fixing Bugs and adding more dials
    [MainWindow.py]
2024-03-18 Fixing bugs for ui
    [MainWindow.py]
2024-03-24 Testing int to str slot fix
    [MainWindow.py]
2024-03-30 database filtering
2024-03-30 fixed empty filter crash
    [database.py]
2024-03-30 Testing Temp Sensors
2024-03-30 fixed union crash bug
    [database.py]
2024-04-09 Adding Elevator Thread
2024-04-09 Fixing Signal for elevator
    [MainWindow.py]
2024-04-09 Fixing index problem derp
    [MainWindow.py]
2024-04-22 pin changes for physical integration
2024-04-26 trying to fix proper clean up
    [MainWindow.py]
2024-04-27 Adding Servo Funcationality
2024-04-28 Fixing Servo stuffs. May break
    [MainWindow.py, background_main.py, tempSensor.py]
2024-04-28 fixed servos on and gate
    [background_main.py, tempSensor.py]
2024-04-29 Fixing neopixel current draw
    [neo_pixel_motion.py]
2024-04-29 fixing Servos
2024-05-01 3d model test
    [Solder Board Peg (x4).step]
2024-05-01 STL test
    [Solder Board Peg (x4).step]
2024-05-01 STL test 2
2024-05-01 STL test 3
    [TridiumFrame Peg (x4).stl]
2024-05-01 All Frame Parts
    [Arduino Peg Mount (x1).stl, Base Frame Clamp (x16).stl, Base Frame Clamp L (x2).stl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]
2024-05-02 Adding PDF Schematic for elevator to elevator code
